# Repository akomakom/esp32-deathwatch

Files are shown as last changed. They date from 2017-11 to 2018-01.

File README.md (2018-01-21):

ESP-IDF Death Watch for the ESP32
====================

This **IoT** project is lovingly called Death Watch because it serves a very simple purpose: 
it reports in-house activities so that some action can be taken should occupants seize to seem alive. 
It is designed to be run on the [Espressif ESP32](http://espressif.com/en/products/hardware/esp32/overview) 
and compiled using the ESP-IDF framework. 

#### Rationale

Although there may be many reasons do this, in my case this IoT project solves the 
*What if I die (or am otherwise detained), in or out of the house, and the pet(s) are left unattended and nobody knows?* dilemma.  It could equally well serve to monitor senile/disabled/elderly individuals (although there are probably better tools).

There are obviously many ways to solve this problem, 
but I wanted something that's more reliable than my phone. 
In fact, I wanted it to rely on as little hardware as possible, 
so I didn't involve any of my own servers or privately hosted code, 
relying instead only on WiFi and Google. 

#### Setup

##### The ESP-32 board is connected to:

* A **motion sensor** (ie HC-SR501) - detects human motion, placed where pets will not trip it (garage in my case)
* An **ultrasonic rangefinder** (ie HC-SR04-P) - detects garage door position (both for fun and to serve its purpose).  Intended to be mounted on the ceiling pointed down, this can then identify 3 states: 
    1. Door open (short distance to door)
    2. Car present (medium distance to car)
    3. Door closed (long distance to floor)
* A **temperature sensor** (DS18B20) - measures garage temperature just for fun.

##### It then does the following:

* **Monitors** above sensors and collects data.
* **Reports** said data periodically via an HTTPS (SSL) POST request (eg: to Google Forms) 
* Also provides a **webserver** that allows said data to be retrieved via HTTP, if you want (JSON).

##### What you do with the data is up to you, but with Google Forms, the idea is to:

* Have time-series data in a spreadsheet (for example, number of motion events for each hour) 
* Run a scheduled Google Script that will send email (for example) when no motion has been detected for X hours.
  * The script could first email you as a warning, and after a further wait - send email to your designated first responders.
  * The script could have a whitelist spreadsheet (eg vacation days when no alarming is needed)
  * The script also sends reminders if the garage door is left open.
* Whatever else.

The above is fully implemented in **google docs**. In fact, there is almost more logic in the spreadsheet and its associated script than there is in this repository.  To access, make a copy (in Google Drive) of [this spreadsheet](https://docs.google.com/spreadsheets/d/1qw4G7kOuIYnGbgxCVbODfhFE31ACRkr1jt2POPAOdRk/edit?usp=sharing) and you should have your own copy of the form and script associated with it. You'll want to set up triggers (in the Script Editor) and thresholds (on the Calculations sheet).  Screenshots from the doc:

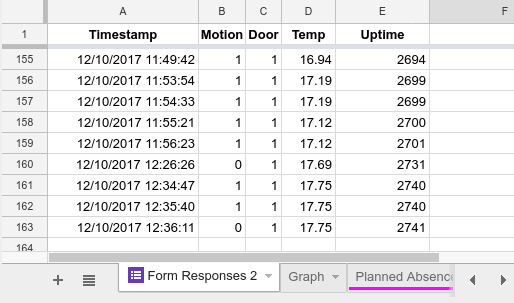
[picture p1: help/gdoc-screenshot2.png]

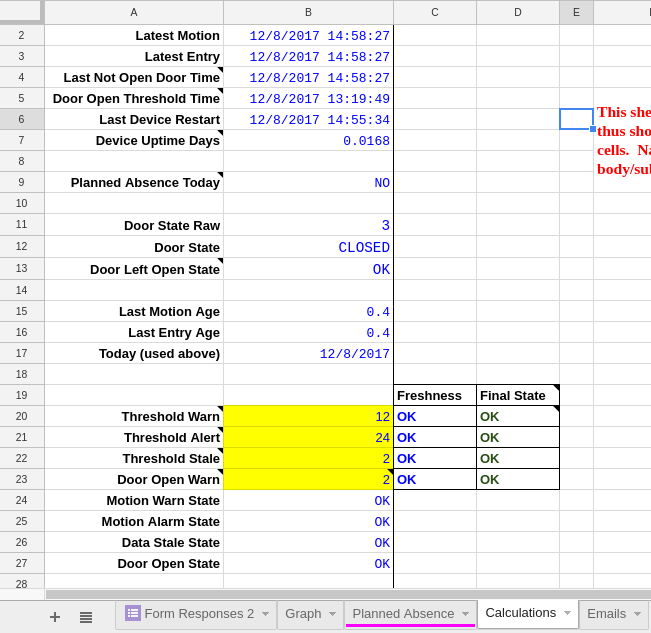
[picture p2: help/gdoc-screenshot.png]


#### Circuit

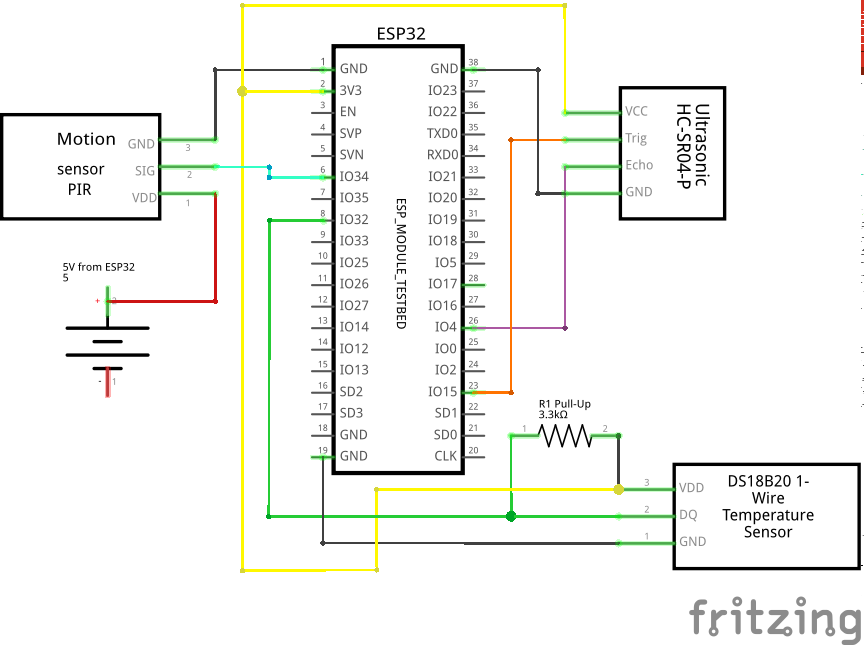
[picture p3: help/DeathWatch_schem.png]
Circuit


The wiring is trivial, sensors are connected to power, ground and GPIO pins.   Some details:

* **HC-SR04-P** rangefinder is happy with 3.3V input and outputs 3.3V signal (I think), so it connects directly to GPIO.  I first used a 5V US-100 rangefinder but it was very unstable (the diagram shows the old wiring).  The HC-SR04-P is like an HC-SR04 but works well at low voltage.
* **HC-SR501** motion detector takes 5V (taken from 5V pin) but outputs 3.3v, so it's just connected directly to GPIO.
* **DS18B20** temperature sensor connects directly to 3.3v power/ground pins and to GPIO for signal, except that a >=3K resistor is used to pull-up (connects signal wire to 3.3v) 

All of the above are standard wiring connections and can be found on the interwebs.  
ADC1 pins are used for all of the above since WiFi is used (see defaults in menuconfig). 

#### Credits

Various components were adapted from:

* https://github.com/feelfreelinux/ds18b20
* https://github.com/cmmakerclub/esp32-webserver
* https://github.com/Ebiroll/esp32_ultra
* ESP32-IDF Examples

#### Prerequisites
This application is meant to be used with `Espressif IoT Development Framework`_ (ESP-IDF) which should be properly installed. 

Please check ESP-IDF docs for getting started instructions.

run "make menuconfig" (a large number of configuration options are found in the DeathWatch menu item):

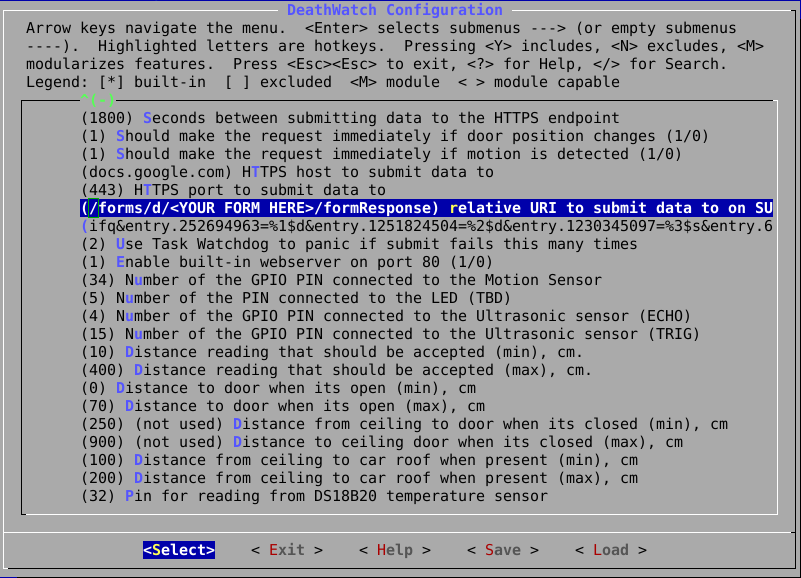
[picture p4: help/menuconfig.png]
menuconfig Menuconfig


#### Additional Possibilities:

* Motion detected LED (either controlled by GPIO or directly form the motion sensor pin, depending on power requirements).
* Car position indicator (far enough into garage), probably with a second ultrasonic module.  This would have to be measuring very frequently to be useful and will need a bright light of some kind to indicate position.
* Configuration via the built-in webserver (flash storage for settings).  
* Control of garage door via webserver (relay to button).  Possibly even automatically close the door if left open.

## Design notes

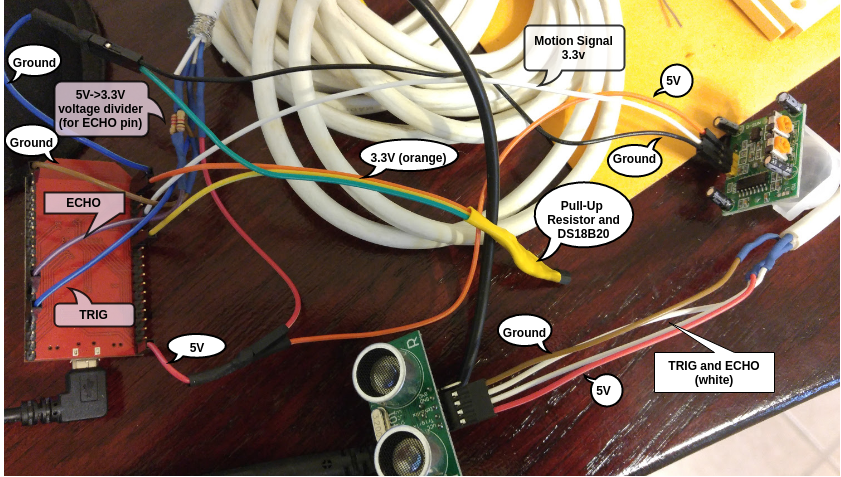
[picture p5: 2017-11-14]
help/circuit.png

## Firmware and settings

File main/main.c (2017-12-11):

#include <stdio.h>

#include "driver/gpio.h"
#include "freertos/FreeRTOS.h"
#include "freertos/task.h"
#include "freertos/semphr.h"


#include "esp_system.h"
#include "esp_event.h"
#include "esp_event_loop.h"
#include "esp_task_wdt.h"
#include "nvs_flash.h"
#include "driver/gpio.h"
#include "driver/uart.h"
#include "esp_log.h"
//#include "driver/adc.h"
#include <sys/time.h>

#include "utils.h"
#include "main.h"
#include "network.h"
#include "client.h"
#include "server.h"
#include "motion.h"
#include "us.h"
#include "temperature.h"

static const char *TAG = "main";

static main_data_t main_data;

void callback_motion_event() {
    ESP_LOGI(TAG, "Motion detected: %d", main_data.motion_count);
	main_data.motion_count++;
	main_data.motion_count_lifetime++;
	main_data.motion_timestamp = esp_log_timestamp();
	if (CONFIG_SUBMIT_ON_MOTION) {
		client_force_request_now();
	}
}

void callback_distance_reading(double distance) {
	static uint8_t newstate = 0;
    if(distance > CONFIG_US_DISTANCE_OPEN_MIN && distance < CONFIG_US_DISTANCE_OPEN_MAX) {
    	newstate = DOOR_OPEN;
    } else if (distance > CONFIG_US_DISTANCE_CAR_MIN && distance < CONFIG_US_DISTANCE_CAR_MAX) {
    	newstate = DOOR_CARPRESENT;
    } else {
    	newstate = DOOR_CLOSED;
    }

    if (newstate != main_data.door) {
    	ESP_LOGI(TAG, "Door state changed from %d to %d (distance: %f)", main_data.door, newstate, distance);
    	main_data.door = newstate;
    	if (CONFIG_SUBMIT_ON_DOOR_STATE_CHANGE) {
    	    client_force_request_now();
    	}
    }

    main_data.door_raw_distance = distance; //saving it as an int for simplicity
    main_data.door_measurement_timestamp = esp_log_timestamp();

    ESP_LOGI(TAG, "Distance: %f cm, Door: %d", distance, main_data.door);
}

void callback_temperature_reading(float temperature) {
    ESP_LOGI(TAG, "Temperature is %f C", temperature);
    main_data.temp = temperature;
    main_data.temp_timestamp = esp_log_timestamp();
}

/**
 * Called to generate the client request body before post request
 */
void callback_gen_http_post_body(char * buf) {
    //big hack because positional printf is broken with %f: https://github.com/espressif/esp-idf/issues/1269
    char temp[10];
	sprintf(temp, "%.2f", main_data.temp);


	sprintf(buf, WEB_POSTDATA_TEMPLATE,
		main_data.motion_count,
		//check for age and report unknown if it's too old
		((esp_log_timestamp() - main_data.door_measurement_timestamp) > (US_READ_DELAY * US_MAX_READING_AGE)) ? DOOR_UNKNOWN : main_data.door,
		((esp_log_timestamp() - main_data.temp_timestamp) > (TEMPERATURE_READ_FREQUENCY * TEMPERATURE_MAX_READING_AGE)) ? TEMPERATURE_BAD_READING_STRING : temp,
		esp_log_timestamp() / 60000);
}

/**
 * Called after client request succeeds
 */
void callback_post_request() {
    main_data.motion_count = 0; //reset data
    main_data.submit_count++;
}

void app_main()
{
    ESP_ERROR_CHECK( nvs_flash_init() );

    //have the watchdog monitor the client task and reboot if it hangs for any reason
    //including failure to connect (but not too frequently)
    uint16_t watchdog_timeout = max(SUBMIT_FREQUENCY * CONFIG_SUBMIT_FAIL_COUNT_PANIC + WATCHDOG_MINIMUM_TIMEOUT, WATCHDOG_MINIMUM_TIMEOUT);
    ESP_LOGI(TAG, "Setting task watchdog timeout to %d seconds", watchdog_timeout);
    ESP_ERROR_CHECK(esp_task_wdt_init(watchdog_timeout, true));


    //initial values
    main_data.temp = TEMPERATURE_BAD_READING;
    main_data.temp_timestamp = 0;
    main_data.motion_count = 0;
    main_data.motion_count_lifetime = 0;
    main_data.motion_timestamp = 0;
    main_data.door = DOOR_UNKNOWN;
    main_data.submit_count = 0;
    main_data.door_measurement_timestamp = 0;
    main_data.server_request_count = 0;

    initialise_wifi();

    initialize_motion(&callback_motion_event);
    initialize_ultrasound(&callback_distance_reading);
    initialize_temperature(&callback_temperature_reading);

    if (CONFIG_SERVER_ENABLE) {
    	//server is currently tightly coupled with our data structure
        start_server(&main_data);
    }
    start_client(&callback_gen_http_post_body, &callback_post_request);
}

void network_stopped_handler() {
//	stop_client(); //sometimes client doesn't work after many restarts
//	stop_server(); //restarting server not working too well
}
void network_started_handler() {
//	start_server(&main_data);
//	start_client(&main_data);
}

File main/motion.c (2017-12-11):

#include <stdio.h>
#include "driver/gpio.h"
#include "freertos/FreeRTOS.h"
#include "freertos/task.h"
#include "freertos/semphr.h"
#include "esp_log.h"

#include "utils.h"
#include "motion.h"


static const char *TAG = "motion";

SemaphoreHandle_t xSemaphore = NULL;


// interrupt service routine, called when the button is pressed
void IRAM_ATTR button_isr_handler(void* arg) {
	
    // notify the button task
	xSemaphoreGiveFromISR(xSemaphore, NULL);
}

// task that will react to button clicks
void motion_handler(void * pvParameters) {
	void (*callback)() = (void *) pvParameters;

	// infinite loop
	for(;;) {
		
		// wait for the notification from the ISR
		if(xSemaphoreTake(xSemaphore,portMAX_DELAY) == pdTRUE) {
		    callback();
		}

		delay(10); //just to rule out busywaiting in corner cases
	}
}


void initialize_motion(void (*callback)()) {

    ESP_LOGI(TAG, "Initializing motion interrupt for pin %d", CONFIG_MOTION_PIN);
	// create the binary semaphore
	xSemaphore = xSemaphoreCreateBinary();

	// configure button and led pins as GPIO pins
	gpio_pad_select_gpio(CONFIG_MOTION_PIN);
//	gpio_pad_select_gpio(CONFIG_LED_PIN);

	// set the correct direction
	gpio_set_direction(CONFIG_MOTION_PIN, GPIO_MODE_INPUT);
//    gpio_set_direction(CONFIG_LED_PIN, GPIO_MODE_OUTPUT);

	// enable interrupt on rising edge for button pin
	gpio_set_intr_type(CONFIG_MOTION_PIN, GPIO_INTR_POSEDGE);


	// start the task that will handle the button
	xTaskCreate(motion_handler, "motion_handler", 2048, callback, 5, NULL);

	// install ISR service with default configuration
	gpio_install_isr_service(ESP_INTR_FLAG_DEFAULT);

	// attach the interrupt service routine
	gpio_isr_handler_add(CONFIG_MOTION_PIN, button_isr_handler, NULL);
}

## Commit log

2017-11-18 server stability and info
    [main.c]
2017-12-01 anti-jitter logic
